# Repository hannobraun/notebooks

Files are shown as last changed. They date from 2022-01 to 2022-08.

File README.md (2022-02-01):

# Notebook

## About

I make notebooks. As a hobby. And I figured, why not make them open source.

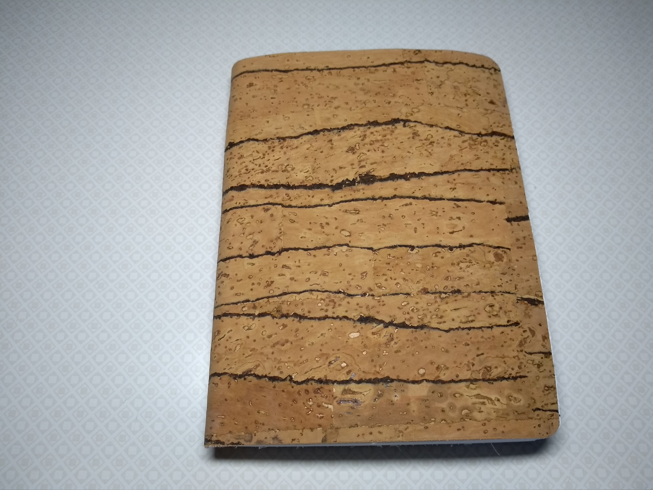
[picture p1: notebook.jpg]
A notebook, closed, bound in cork leather.


In a literal sense, a notebook isn't hardware. But this is still an open-source hardware project, in the sense of ["anything physical that has public source files"][OSHWA FAQ]. I plan to include all information that is required to make these notebooks here in this repository. Tools used, materials and how to source them, and build instructions. The designs of any custom tools I make will also be open source.

[OSHWA FAQ]: https://www.oshwa.org/faq/

## Documentation

The following documentation is available in separate files in the `documentation/` directory:

- Tools: [`documentation/tools.md`](documentation/tools.md)
- Materials: [`documentation/materials.md`](documentation/materials.md)
- Build process: [`documentation/build-process.md`](documentation/build-process.md)
- Improvements to be made: [`documentation/improvements.md`](documentation/improvements.md)

## Work Log

I keep a work log of my notebook builds (and related activities) in [`work-log.md`](work-log.md).

## License

This project is open source, licensed under the terms of the [Zero Clause BSD License] (0BSD, for short), with the addition that the word "software", as used in the license, refers to all copyrighted material in the [`documentation/`](documentation) folder.

This basically means you can do anything with this project, without any restrictions, but you can't hold the authors liable for problems.

See [LICENSE.md] for more details.

[Zero Clause BSD License]: https://opensource.org/licenses/0BSD
[LICENSE.md]: LICENSE.md

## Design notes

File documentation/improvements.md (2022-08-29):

# Improvements

## Process

- Consider pressing each signature separately, before sewing
  That might reduce the overall thickness at the spine.
- Build jig to precisely fold signatures
- Try preparing the cover before glueing
  https://www.youtube.com/watch?v=zemN8_-q2zs
- Use thick paper in the right size and thickness
  Again, would save some preparation work.
- Find better way to cut off material
  Using a knife is tedious and requires sanding afterwards. While that gives the notebook a rough appearance that I kinda like, it would be nicer to just cut if off straight, in one go, using a specialized tool.

  ## Tools

  - The hole guide doesn't work perfectly
    It's too easy to enlarge the holes accidentally. It might work better to have a funnel-like shape, as long as that works with the total length of the drill bit.
    Long-term, a harder material would be good, but that should come after prototyping.

## Product

- Consider using lighter paper
  The A5 paper is a bit heavier (120g/m²) than normal paper (80g/m²). I have yet to see how the end product turns out, but the added thickness certainly makes the problems with the spine worse.
- Make sure spine is straight, and there's not a large gap to the cover
- Make sure the spine can bend sufficiently
  It doesn't bend as well as a Moleskine does. It's fine when writing on the side of the notebook that has more pages, but when writing side, it's significantly less comfortable than a Moleskine.
  Maybe the problem is that the spine is too strong. Maybe I should not glue it at all, and just rely on the sewing. Another idea is to try and flatten the bend of the signatures better. Not sure if that will help, but the Moleskine's signatures are significantly flatter there.
- Use pre-printed pages
  I'd like to have the page number on each page, as well as a subtle grid pattern.

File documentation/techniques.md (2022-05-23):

# Techniques

These are specific techniques that are required in the build process. They can be documented here separately, as they are self-contained, and can be used and practiced independently from the build process.

The build process documentation refers to them here, to keep that documentation reasonable clear.

## Paper preparation

### Folding

1. Push a shorter edge of the paper against the straight edge of the aluminium block.
2. Fold over the opposite edge, also push it against the straight edge.
3. Once both of the paper edges line up, push down on the paper to prevent it from moving.
4. Run your thumbs along the folded end of the paper, while still pushing on the paper with the rest of your fingers.

### Cutting in half

1. Fold the piece of paper.
2. Unfold it again.
3. Place the paper flat on the work surface; the outside of the fold on the bottom.
4. Place the straight edge of the aluminium block on the fold.
5. Cut along the fold, using the aluminium block as a ruler.

## Sewing

### Double-threading a needle

Follow the instruction in this video:
https://www.youtube.com/watch?v=H8wlmwZC_g4

In addition to making a making the knot, make a second knot around the first one. The combined knots should be thick enough to not go through the sewing holes, which is important.

### Sewing the first signature

Sewing the first signature of the text block is different from sowing the other ones. Each signature is sewn to the previous ones, and this obviously can't work with the first.

The goal with sewing the first signature is to establish a sort of base that the following signatures can connect to.

Follow the technique in this video (the video explains the whole sewing process; the link points directly to the sewing technique for the first signature):
https://www.youtube.com/watch?v=XGQ5P8QVHSg&t=96s

### Sewing the second signature

The sewing of the second signature is closer to the other ones, but still a bit different, as the regular technique relies on there being two previous signatures.

Follow the technique in this video (the video explains the whole sewing process; the link points directly to the sewing technique for the second signature):
https://www.youtube.com/watch?v=XGQ5P8QVHSg&t=157s

### Sewing the rest of the signatures

The rest of the signatures are all sewn the same. They all connect to the previous signatures in the same way.

Follow the technique in this video (the video explains the whole sewing process; the link points directly to the regular sewing technique):
https://www.youtube.com/watch?v=XGQ5P8QVHSg&t=222s

### Switching the thread

During the sewing of the signatures, you will run out of thread. While you could use a thread long enough to prevent that from happening, such a long thread is very cumbersome and awkward to use, and it will form unintended knots all the time. Overall, this causes more work than switching the thread a few times.

Follow the technique in this video (the video explains the whole sewing process; the link points directly to the switching of the thread):
https://www.youtube.com/watch?v=XGQ5P8QVHSg&t=311s

## Glueing

### Applying glue

1. Squeeze some glue out of the bottle, roughly distributing it over the whole area that needs to be glued. If you're not sure how much to use, err on the lower side. You can always add more later.
2. Then use the brush to distribute it more evenly, until it covers the whole surface.
3. If necessary, add more glue from the bottle where needed, and distribute that with the brush.
4. To the glue-up directly after. Directly after that, clean the brush (see next section).

### Cleaning the brush

1. Get a small container with enough water in it to submerge the bristles completely.
2. Move the brush around in the water.
3. Keep moving it around in the water, while pressing against the bottom of the container
4. Wipe the bristles off against the rim of the container. It helps if that rim is sharp, and has an overhang towards the inside of the container.
5. Repeat steps 2. to 4. until the brush is clean.
6. Put the brush down and let it dry.

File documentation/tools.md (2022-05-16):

# Tools

## Custom-built

So far, I've made the following tools:
- A simple [book press](tools/book-press.md)
- A drill guide

## Specific tools

I've bought these specifically for making notebooks. I've linked the source I bought them from for each.

- [Awl](https://www.modulor.de/en/awl-l-125-mm-incl-point.html)
- [Bookbinding needles](https://www.modulor.de/en/bookbinding-needle-l-62-mm-o-1-2-mm.html)
- [Corner punch for rounded corners](https://www.modulor.de/en/corner-punch-for-roundeed-corners-radius-ca-10-mm.html)
- [Brush for applying glue](https://www.schmedt.de/da-vinci-forte-synthetics-serie-364-flachpinsel-mit-robusten-rotbraunen-synthetikfasern/61361012)

## Other

These are just standard tools that I already had in my workshop, or found around the apartment.

- A benchtop drill press
  - 1.5mm drill
- A knife
- A ruler
- A pencil
- A combination square
- Coarse sandpaper (P40)
- An aluminium block
  With a straight edge, heave enough to not push it around when you fold paper against it.
- Parchment paper

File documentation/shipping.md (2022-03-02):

# Shipping

I haven't shipped those yet. I'm looking to try these envelopes:
https://www.amazon.de/Netuno-Versandtaschen-haftklebend-Foto-Dokumenten-Versandtaschen-Wandkalender/dp/B097LKBCL6/

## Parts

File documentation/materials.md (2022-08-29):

# Materials

These are the materials required to make a notebook. I've linked the source for anything I've specifically bought. Anything without a link, I already had.

- [Regular paper (A5)](https://www.amazon.de/Druckerpapier-Gesch%C3%A4ftspapier-Laserpapier-Universalpapier-Werbebl%C3%A4tter/dp/B08TTF5LPV/)
- Thick paper (A4): I'm using some old printer paper from the 90s I found. It's a bit thicker than modern printer paper.
- [Binder's thread](https://www.modulor.de/en/linen-binder-s-thread-th-0-42mm-type-30-3-150m-black.html)
- PVA glue
- [Bookmark ribbon](https://www.schmedt.de/zeichenlitze-lesezeichenband-spitzenqualitaet/50825483)
- [Roll of mull, 60mm wide](https://www.schmedt.de/heftgaze-in-schmalrollen-dreifaedig-3-kettfaeden/2651-060)
- [Rubber band](https://www.schmedt.de/gummilitze-flach-umsponnen-mit-einem-farbigen-faden/51865002)
- [Cork leather](https://cork-shop.com/Korkleder-Korkstoff-vegan-Leder-naehen-basteln-kreativ-viele-Designs-und-Abmessungen-Cactus-70x50cm_1)

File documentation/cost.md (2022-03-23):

# Cost

## Material

- A4 paper (regular): 500 sheets = 7.84€ => 24 sheets = ~0.32€
- A4 paper (thick): no idea, but should be close to 0
- Binder's thread: 150m = 9.90€ => 4m (conservative estimate) = ~0.22€
- Bookmark ribbon: 25m = 8.65€ => 0.24m = ~0.08€
- Mull: 50m = 11.64€ => 0.135m = ~0.03€
- Cork leather: 1 sheet = 15.98€ => 1/8 sheet => ~2€

Total: 2.65€ (excluding VAT and material shipping costs)

## Shipping

- Envelope: 10 envelopes = 5.29€ => 1 envelope = ~0.53€
- Postage:
  - to Germany: 2.70€ (Deutsche Post, Großbrief 500g + Prio; VAT not applicable)

Total: 3.23€

## Tools

Didn't calculate. Probably limited, as I'm not using anything fancy, but still outsized cost per notebook.

## Time

It's a hobby, so there's really no basis for calculation.

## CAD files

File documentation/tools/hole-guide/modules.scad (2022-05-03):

// Dimensions of A5 (ISO 216) paper
a5 = [148, 210];

// Intended print settings
layer_height    = 0.25;
extrusion_width = 0.45;

wall_angle  = 60;
wall_height = 10;
wall_top    = extrusion_width * 2;
wall_slope  = wall_height / tan(wall_angle);
wall_total  = wall_top + wall_slope;

work_area = [
    a5.x,
    a5.y * 0.75,
];

base_size = [
    work_area.x + wall_total,
    work_area.y + wall_total,
    layer_height * 4,
];

hole_diameter = 1.5;
hole_offset   = hole_diameter * 3;

hole_distance_nominal = 20;
num_holes             = round(a5.x / hole_distance_nominal / 2) * 2;
hole_distance_actual  = a5.x / num_holes;


$fn = 60;


module bottom() {
    difference() {
        union() {
            base();

            translate([0, 0, base_size.z])
            union() {
                translate([-wall_total, 0, 0])
                front_wall(base_size.x - wall_total);

                translate([0, wall_total, 0])
                side_wall(base_size.y - wall_total);

                intersection() {
                    front_wall(wall_total);
                    side_wall(wall_total);
                }
            }
        }

        translate([0, wall_total + a5.y / 2, 0])
        holes();
    }

    module base() {
        cube(base_size);
    }

    module front_wall(length) {
        translate([base_size.x, wall_total, 0])
        rotate([0, -90, 0])
        rotate([0, 0, -90])
        wall(length);
    }

    module side_wall(length) {
        translate([base_size.x - wall_total, length, 0])
        rotate([90, 0, 0])
        wall(length);
    }

    module wall(length) {
        linear_extrude(length)
        polygon([
            [         0,           0],
            [wall_total,           0],
            [  wall_top, wall_height],
            [         0, wall_height],
        ]);
    }
}

module top() {
    difference() {
        cube([
            work_area.x,
            work_area.y,
            layer_height * 4,
        ]);

        translate([0, a5.y / 2, 0])
        holes();
    }
}

module holes() {
    for (i = [1:num_holes]) {
        translate([hole_distance_actual * (i - 0.5), 0, 0])
        cylinder(d = hole_diameter, h = base_size.z * 4, center = true);
    }
}

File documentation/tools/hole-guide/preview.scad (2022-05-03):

include <modules.scad>;

bottom();

translate([0, wall_total, base_size.z * 2])
top();

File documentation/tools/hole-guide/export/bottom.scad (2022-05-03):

use <../modules.scad>

bottom();

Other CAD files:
documentation/tools/hole-guide/export/top.scad

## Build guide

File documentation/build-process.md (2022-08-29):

# Build Process

This documentation of the build process is incomplete. For now, please refer to [my build report of the first notebook](https://hanno.braun-odw.eu/notes/notebook/). As I make more notebooks, I will document the process more thoroughly here.

Please refer to the documents about tools, materials, and techniques, which these steps refer to.

## Prepare the signatures

1. Take 48 sheets of paper.
2. Drill holes into the whole stack, using the hole guide.
3. Fold the drilled sheets.
   1. Take a stack of 4 sheets of paper.
   2. Fold the 4 sheets of paper together .
   3. Repeat until all sheets of paper are folded.

The signatures are now ready for sewing.

## Create the text block

1. Cut off a bit over two arm's length of thread from the spool.

By making it a bit over two arm's lengths, it becomes a bit over one arm's length after you double it up in the next step. This is comfortable to handle, while long enough to not requiring too much re-threading

2. Double-thread the needle. See Techniques -> Sewing.
3. Sew the signatures. See Techniques -> Sewing.
4. Put the text block into the book press, to hold it in place.
5. Align the signatures, so the spine forms as straight a wall as feasible.

It doesn't need to be perfect. Just do the best you can, and make sure no signatures are hidden because they are recessed.

6. Clamp down the book press.
7. Apply two layers of PVA glue to the spine. Let each dry for 30 minutes.

## Add the end pages

1. Cut a thick sheet of paper in half, resulting in two A5-sized sheets.
2. Fold those A5-sized sheets.

The two resulting sheets will be used as the end pages. Those are doubled up on each side, to prevent strain from opening the cover to transfer to and damage the text block.

3. Lay the two end pages on top of each other, so one covers the other.
4. Move the top end page, so a part of it along a longer edge sticks out.

The part that sticks out should be a roughly 5mm broad strip along the folded end.

5. Apply glue to that 5mm strip of the bottom end page.
6. Switch their positions.

Now the page with the glue applied should be on top. The strip of the bottom page that sticks out below the top page should be next to the strip of the top page that has glue applied.

7. Apply glue to the strip of the bottom page.

If you've done this correctly, you've applied glue to a 5mm strip along the folded edge of both end pages, without accidentally applying it anywhere else on the end pages.

8. Glue the end pages onto both sides of the text block.

The glued strips should be parallel to the spine, and the edges on the side should line up with the edges of the spine.

9. Press the end pages onto the text block for a moment, using your hands.

Do not use the book press for this, or you'll glue the text block to the book press.

## Strengthen the spine and add the bookmark

1. Cut off ~240mm of bookmark ribbon.
2. Cut off ~135mm of mull.
3. Fold the piece of mull in half along the long axis, to mark its middle.

The goal is to place the mull so that is is centered on top of the spine, along both axes.

4. Put text block into the book press.

It should stick out far enough, so the mull can be glued on.

5. Apply glue to the spine of the text block, where the mull will go.
6. Place bookmark ribbon on the spine, coming from a shorter edge.

~10mm of the bookmark ribbon should stick into the glued area.

7. Use the brush to press the bookmark ribbon into the glue.
8. Place the mull on the spine, so it is centered along both axes.
9. Apply glue to the mull, where it touches the spine.

Use the brush to push the mull onto the spine, so there are no creases.

10. Glue one flap of the mull onto the respective end page.

Again, use the brush to prevent creases in the mull.

11. Repeat with the other flap.
12. Keep applying glue, until the mesh structure is almost not visible any more.
13. Let it dry for 30 minutes.

## Finish the text block

1. Use sandpaper to sand the short sides of text block, neighboring the spine.

It doesn't need to be perfect, but any crevices should be evened out. Use combination square from the spine to figure out how the side should be oriented, if necessary.

2. Use sandpaper to sand long side of the text block, opposite the spine.

Use combination square from one of the sides to figure out orientation, if necessary.

3. Round all corners with the corner punch

## Start adding the cover

1. Cut out a rectangular piece of cork.

It should be big enough, that it will protrude everywhere after you glued it to the text block.

2. Put a sheet of parchment paper between one end page and rest of text block.

The sheet should be big enough to stick out on all sides under the end page.

3. Apply PVA glue to the front side of the text block.
4. Glue cover onto the front side side.
5. Clamp in book press, let it dry for 30 minutes.

Glueing the front side first, gives you the opportunity to add the rubber band for keeping the notebook closed.

## Add the rubber band

1. Put back side of the cover onto text block, where you will glue it later.
2. With a pencil, draw outline of text block onto inside of back side of cover.

This will result in three lines on the inside of the text block: One parallel to the outer side (the one opposite the spine), one parallel to the upper side, one parallel to the lower side. For simplicity, we'll call those the outer, upper, and lower line.

3. Draw another line parallel to the outer line, in the direction of the spine.

The parallel line should be 20 mm from the outer line.

4. On parallel line, mark the spots 15 mm from the upper and lower lines.
5. At these markings, cut slits that are parallel to the upper and lower lines.

The slits should be just broad enough for the rubber band to fit through.

6. Cut of 15 cm of the rubber band.
7. Put ends of the rubber band through the slits, from outside to inside
8. Pull ends towards the inside, until rubber band feels tight enough.

It should be tight enough to comfortably keep the notebook closed, once everything is glued together.

9. Glue ends of rubber band to inside of cover. Let it dry for 30 minutes.

## Finish adding the cover

1. Apply PVA glue to the inside of the cover, where it will touch the spine.
2. Put parchment paper under the other end page.
3. Apply PVA glue to that side of the text block.
4. Press cover onto text block, starting at the already glued side.

By starting at that side, and moving over the spine, towards the free end of the cover, you minimize the gap between cover and spine.

5. Clamp in book press, let it dry for 30 minutes.

## Cut cover to size

Now the cover needs to be cut to size, so it doesn't stick out of the text block. This didn't work out so well for notebook #4, so I'll keep experimenting with techniques.

This is it, done!

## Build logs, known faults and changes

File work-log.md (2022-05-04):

# Work Log

I have a daily habit of working on side projects. These projects used to be all software, and I made sure to make at least one useful commit every single day.

As I move more into physical projects, this doesn't work as well. But I do really like that daily commit as a way to track my habit, and I've decided I want to keep it. Hence this work log. Whenever I do work on this project that otherwise wouldn't result in a commit to this repository, I document it here.

## 2022-05-04

Printed the new prototype for the hole jig. Looks good so far. Will try it out on the weekend.

## 2022-04-30

Tried using the hole drilling jig. The paper stack doesn't fit in it, which is a showstopper problem. I have ideas for a design that is less reliant on high precision.

## 2022-04-24

Printed the fixed top part. Holes are lining up now.

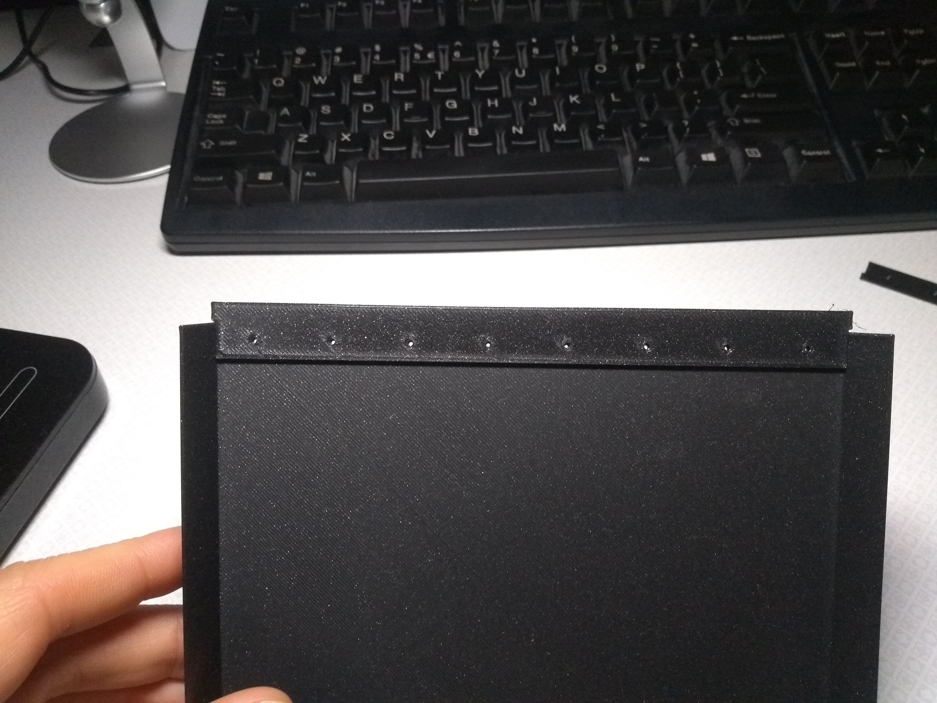
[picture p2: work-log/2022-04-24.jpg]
The two parts of the hole drilling jig, holes lining up


## 2022-04-22

Printed the new jig. I can already tell it's too flimsy, but it'll do for a first try. The holes of the top and the bottom parts don't line up though. I'll need to correct that.

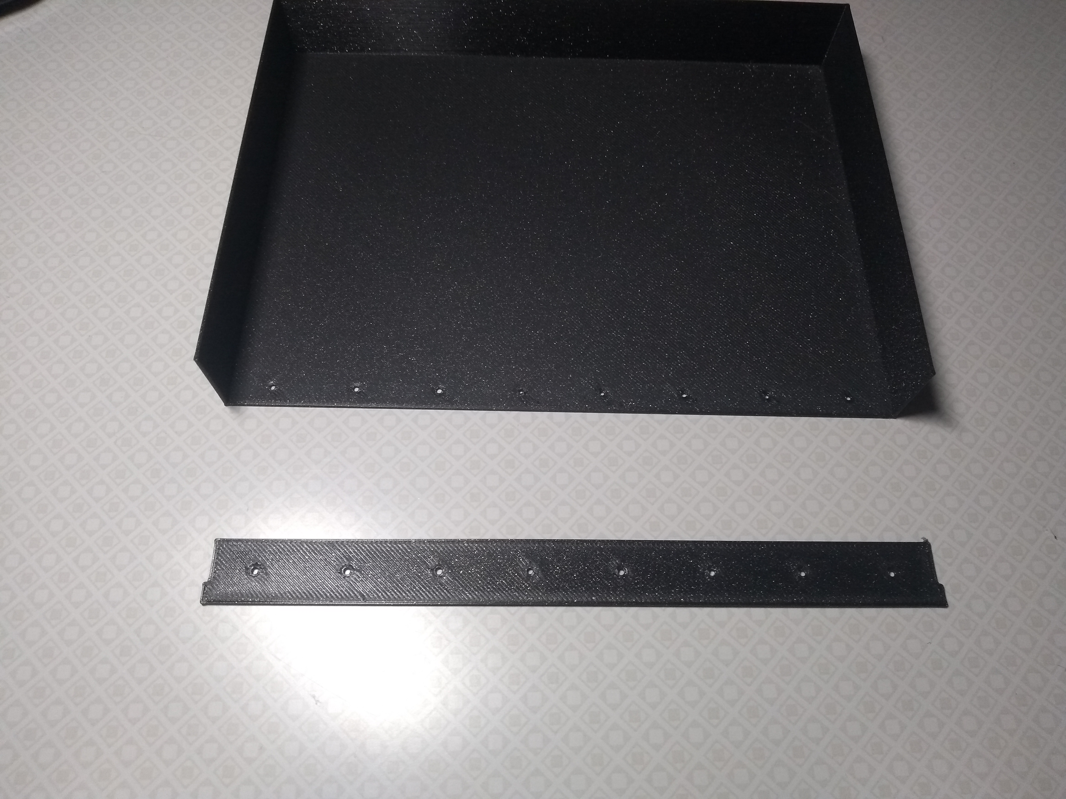
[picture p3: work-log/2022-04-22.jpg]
A jig for drilling the required holes into paper


## 2022-04-19

Continued sketching the new jig. Getting close to a minimalist design that I like.

## 2022-04-18

Started sketching a new jig, this time for drilling the holes.

## 2022-04-17

After running into problems with the jig I've been designing, I've started experimenting with drilling holes into the paper instead of puncturing it with an awl. Excellent first result. Very happy with the quality of the hole.

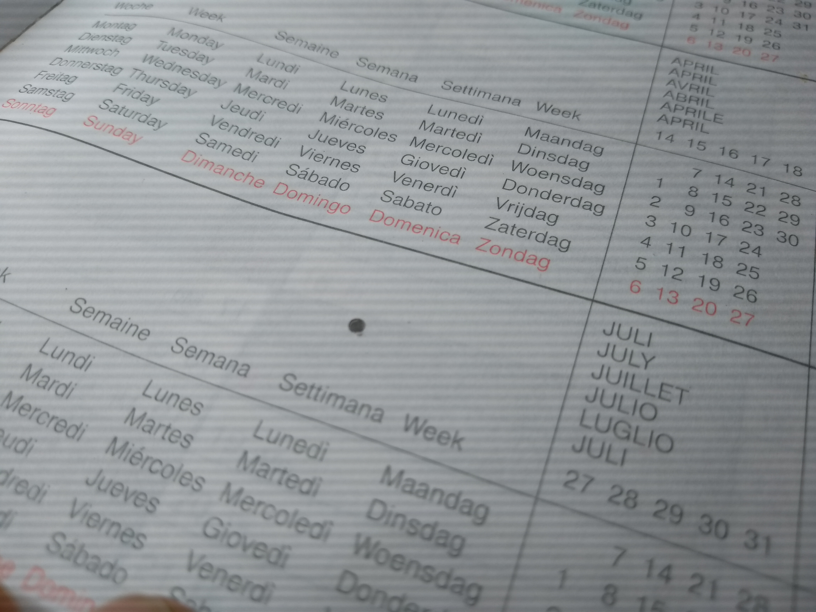
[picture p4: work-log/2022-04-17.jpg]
A small round hole in a piece of paper


Used an 1.5mm drill, 8.500 rpm.

## 2022-04-02

Experimented with glueing PLA parts, which will be necessary for assembling the puncturing jig. Results: Acetone worked relatively well, hot glue and PVA glue didn't.

Pairs of PLA parts glued together, on a workbench

## 2022-03-24

Shipped notebook #4.

## 2022-03-18

Finished notebook #4.

Notebook #4, finished

## 2022-03-13

Continued working on notebook #4. Tried a new approach this time: Finishing the text block before adding the cover.

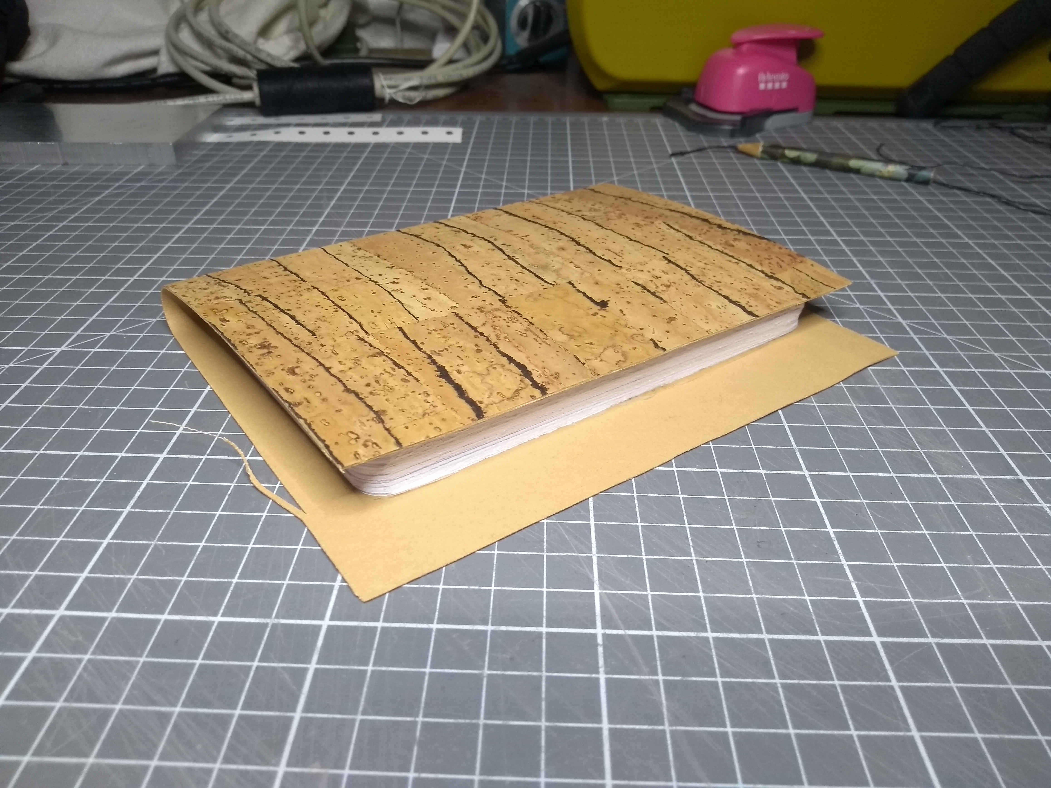
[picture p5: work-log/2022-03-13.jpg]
Notebook #4; cover not yet cut to size


## 2022-03-12

Continued working on notebook #4. Glued on the bookmark and mull.

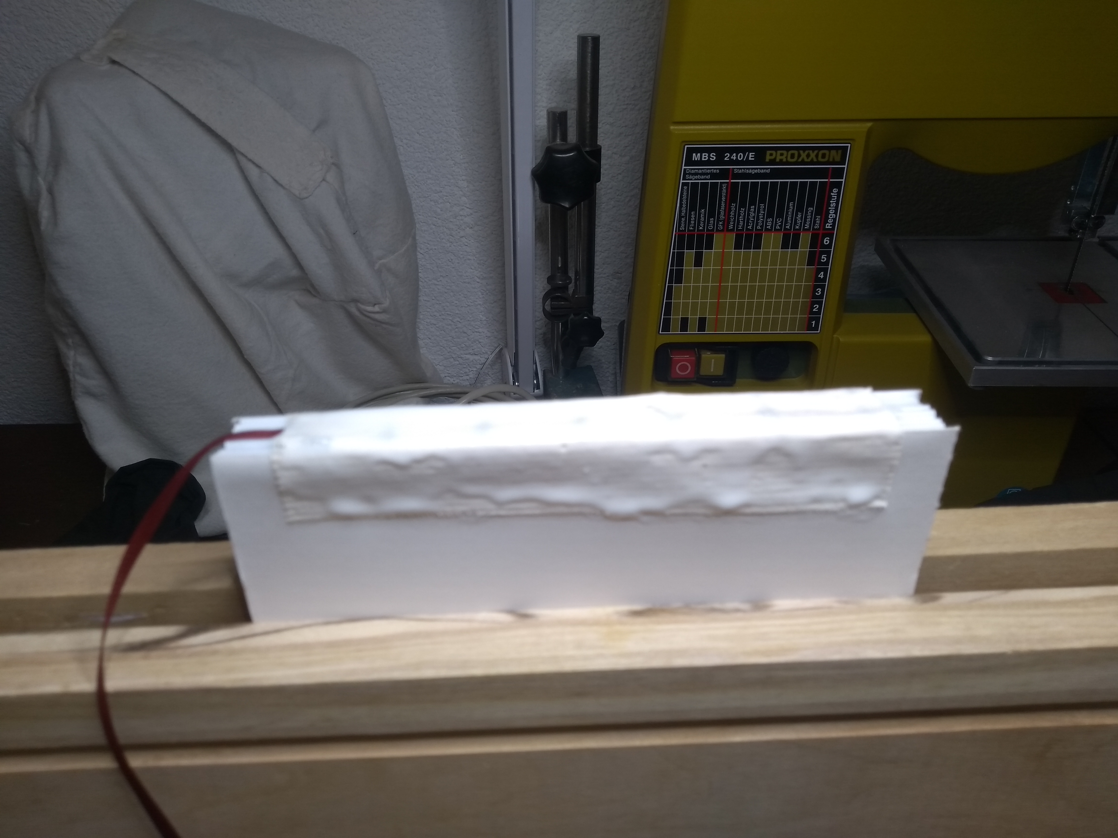
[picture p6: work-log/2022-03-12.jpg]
Notebook #4's text block with the mull glued on


## 2022-03-11

Continued working on notebook #4. Glued on the end pages.

## 2022-03-10

Finished sketching concept for the hole-making jig. Probably ready for CAD modeling, unless I get some more ideas before I get a chance to do that.

## 2022-03-09

Started sketching a jig that I want to use for puncturing the sheets, possibly for folding them. Sketched in notebook #1, of course.

## 2022-03-08

Shipped notebook #3.

## 2022-03-07

Got notebook #3 ready for shipping.

## 2022-03-06

Progress on notebook #4. Finished sewing the text block.

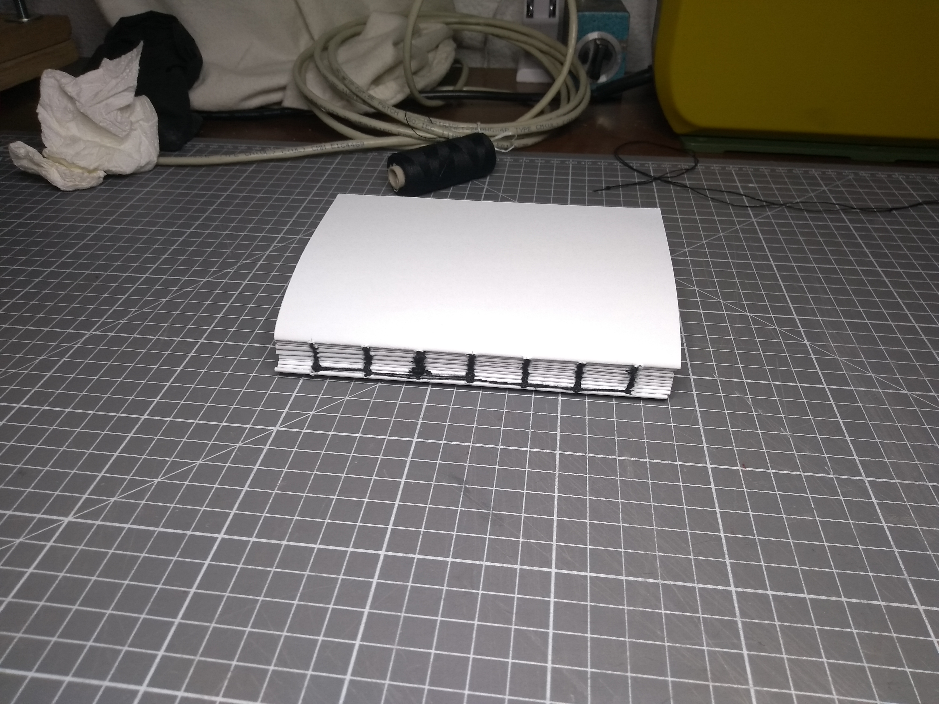
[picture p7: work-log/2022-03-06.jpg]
The sewn text block of notebook #4


## 2022-03-01

Started working on notebook #4. Tried some process improvements to create the signatures. Worked out well.

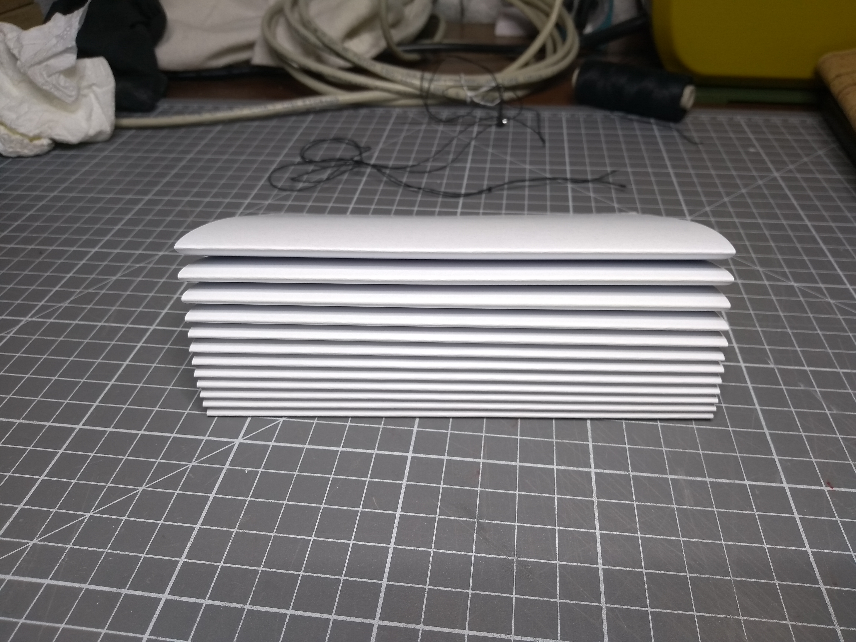
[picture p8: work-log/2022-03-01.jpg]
Stack of signatures for notebook #4


## 2022-02-26

Finished notebook #3. This is the first one with a bookmark.

Notebook #3, finished

## 2022-02-13

Glued the cover on notebook #3. Started finishing it.

## 2022-02-12

Continued working on notebook #3. Glued the spine; glued on the end pages and the mull. It's ready for glueing on the cover now.

## 2022-02-06

Started working on notebook #3. Finished sewing the text block.

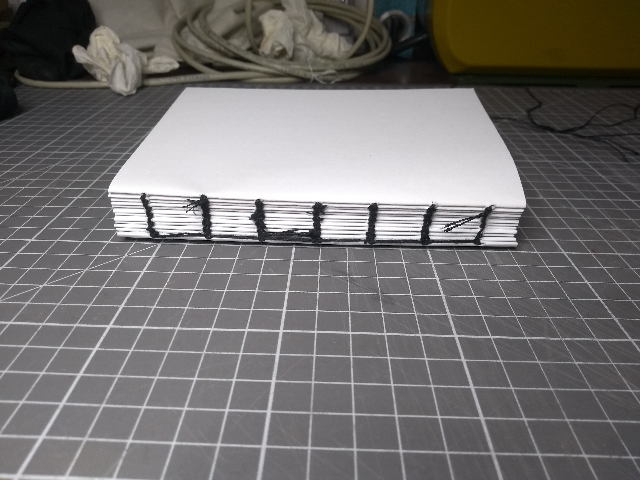
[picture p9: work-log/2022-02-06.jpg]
Notebook #3, text block sewn


## 2022-02-01

Ordered more cork (my initial order lasted for 2 notebooks). Did research about materials I can use for the bookmark, and some kind of flexible ribbon to keep the notebook closed, but couldn't find anything I was happy with.

## 2022-01-30

Finished notebook #2.

Notebook #2, finished

## 2022-01-29

Finished sewing and glueing notebook #2.

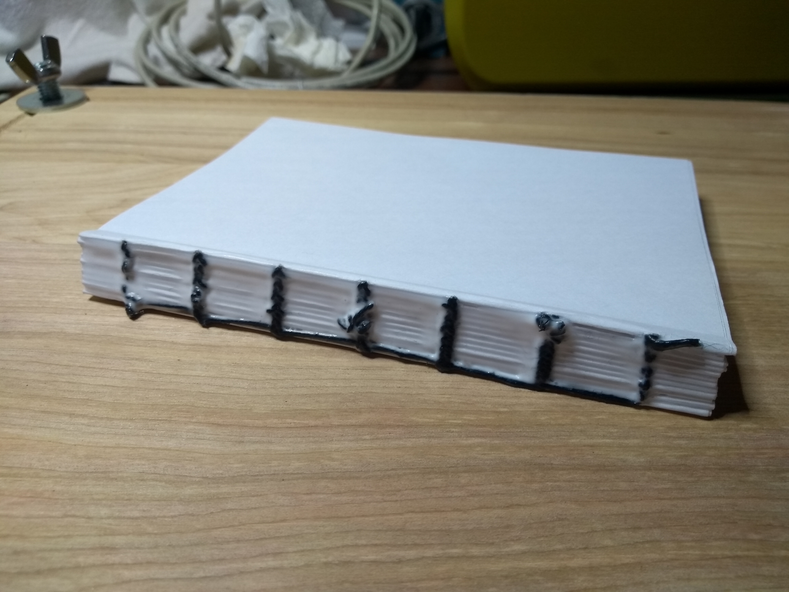
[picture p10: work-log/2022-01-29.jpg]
Notebook #2, sewed and glued


## 2022-01-23

Finished the signatures for notebook #2. Should be ready for sewing.

## 2022-01-22

Worked on creating the signatures for notebook #2. Spent a lot of extra time because I did the operations in the wrong order.

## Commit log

2022-01-23 Document materials
2022-01-30 Update materials
2022-02-01 Update cork leather
    Switched to the bigger size. Should be good for at least 8 notebooks
    instead of 2.
2022-02-08 Add potential materials for product improvements
2022-02-17 Document length of thread to cut off
2022-02-17 Add separate file for techniques
    Start with basic documentation about double-threading the needle.
2022-02-20 Document glueing techniques
2022-02-22 Update build process steps for glueing end pages
2022-02-22 Add mull to materials
2022-03-04 Add bookmark ribbon to materials
2022-03-14 Start designing puncturing jig
    [model.scad]
2022-03-15 Add gap around the paper
    [model.scad]
2022-03-15 Split material length into 2 variables
    [model.scad]
2022-03-15 Redefine material strength from print settings
    [model.scad]
2022-03-16 Add tasks
    [model.scad]
2022-03-26 Restart work on the puncturing jig
    The current (unfinished) model is too big to print, and I don't like the
    current code enough to want to adapt it.
    [model.scad]
2022-03-26 Add some measurements
    [model.scad]
2022-03-26 Round one corner
    [model.scad]
2022-03-26 Round other corner
    [model.scad]
2022-03-26 Add second base
    [model.scad]
2022-03-26 Add walls
    [model.scad]
2022-03-26 Subtract inner space
    [model.scad]
2022-03-26 Fix height calculation
    [model.scad]
2022-03-26 Rename module
    [model.scad]
2022-03-26 Add additional rib
    [model.scad]
2022-03-27 Fix height of horizontal ribs
    [model.scad]
2022-03-28 Move task
    [model.scad]
2022-03-28 Add vertical rib
    [model.scad]
2022-03-28 Add more vertical ribs
    [model.scad]
2022-03-28 Update task
    [model.scad]
2022-03-28 Fix positioning of vertical ribs
    [model.scad]
2022-03-29 Update variable name
    [model.scad]
2022-03-29 Add pair of side ribs
    [model.scad]
2022-03-29 Fix calculation of number of front ribs
    [model.scad]
2022-03-29 Change how vertical side ribs are placed
    [model.scad]
2022-03-29 Add side ribs
    [model.scad]
2022-03-30 Add corner rib
    [model.scad]
2022-03-30 Add other corner rib
    [model.scad]
2022-03-30 Remove completed task
    [model.scad]
2022-03-30 Remove commented code
    [model.scad]
2022-03-31 Adjust placement of side ribs
    [model.scad]
2022-03-31 Improve corners
    [model.scad]
2022-03-31 Add placeholder module for connector
    [model.scad]
2022-04-01 Fix manifoldness issues in corner ribs
    [model.scad]
2022-04-01 Rename variable
    [model.scad]
2022-04-01 Improve variable names
    [model.scad]
2022-04-01 Add connector
    [model.scad]
2022-04-04 Add base of inner jig
    [inner.scad, model.scad]
2022-04-05 Increase roundness
    [model.scad]
2022-04-05 Add holes
    [inner.scad, model.scad]
2022-04-06 Rename modules
    [inner.scad]
2022-04-06 Add awl guides
    [inner.scad]
2022-04-09 Add task
    [inner.scad]
2022-04-10 Add ribs
    [inner.scad, model.scad]
2022-04-10 Make sure number of front ribs is uneven
    This way, they won't interfere with the holes.
    [inner.scad, model.scad]
2022-04-12 Add missing rib
    [inner.scad]
2022-04-13 Update awl diameter
    [inner.scad]
2022-04-13 Load parameters from a central file
    [common.scad, inner.scad, model.scad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]
2022-04-20 Start designing new hole jig
    [preview.scad]
2022-04-20 Add module
    [preview.scad]
2022-04-20 Add module for holes
    [preview.scad]
2022-04-21 Model top part of hole jig
    [preview.scad]
2022-04-22 Fix top position
    [preview.scad]
2022-04-22 Add guide piece for lining up bottom and top
    [preview.scad]
2022-04-22 Move modules to dedicated file
    [modules.scad, preview.scad]
2022-04-22 Add files for exporting the individual parts
    [bottom.scad, top.scad]
2022-04-23 Move top part down
    This makes it easier to see if the holes are lined up. (They aren't.)
    [preview.scad]
2022-04-23 Fix hole position of top part
    [modules.scad]
2022-04-24 Remove abandoned puncturing jig
    [common.scad, inner.scad, model.scad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]
2022-05-01 Rename directory
    [bottom.scad, modules.scad, preview.scad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]
2022-05-01 Start next version of hole drilling jig
    [preview.scad]
2022-05-01 Remove debug output
    [preview.scad]
2022-05-01 Add wall
    [preview.scad]
2022-05-01 Add corner
    [preview.scad]
2022-05-02 Make base large enough to support full sheet width
    [preview.scad]
2022-05-02 Set accuracy
    [preview.scad]
2022-05-03 Add top
    [modules.scad, preview.scad]
2022-05-03 Add export files
    [bottom.scad, top.scad]
2022-05-04 Remove old version of hole jig
    [bottom.scad, modules.scad, preview.scad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]
2022-05-16 Update directory name
    [bottom.scad, modules.scad, preview.scad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]
